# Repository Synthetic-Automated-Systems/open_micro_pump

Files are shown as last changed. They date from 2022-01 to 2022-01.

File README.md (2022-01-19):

# Open Source Microfluidic Pump

Welcome to the official repository for _Open-source, 3D-printed Peristaltic Pumps for Small Volume Point-of-Care Liquid Handling._  This repository serves as an addendum to the paper [Behrens et al.](https://www.nature.com/articles/s41598-020-58246-6) published in Scientific Reports in 2020. This repository hosts the original STL files presented in Behrens et al. (pump 1.0), along with instructions for assembling the pump. Additionally, this repository hosts parts for an updated design (pump 1.1), which provides improved functionality while signifigantly reducing the cost per pump. 
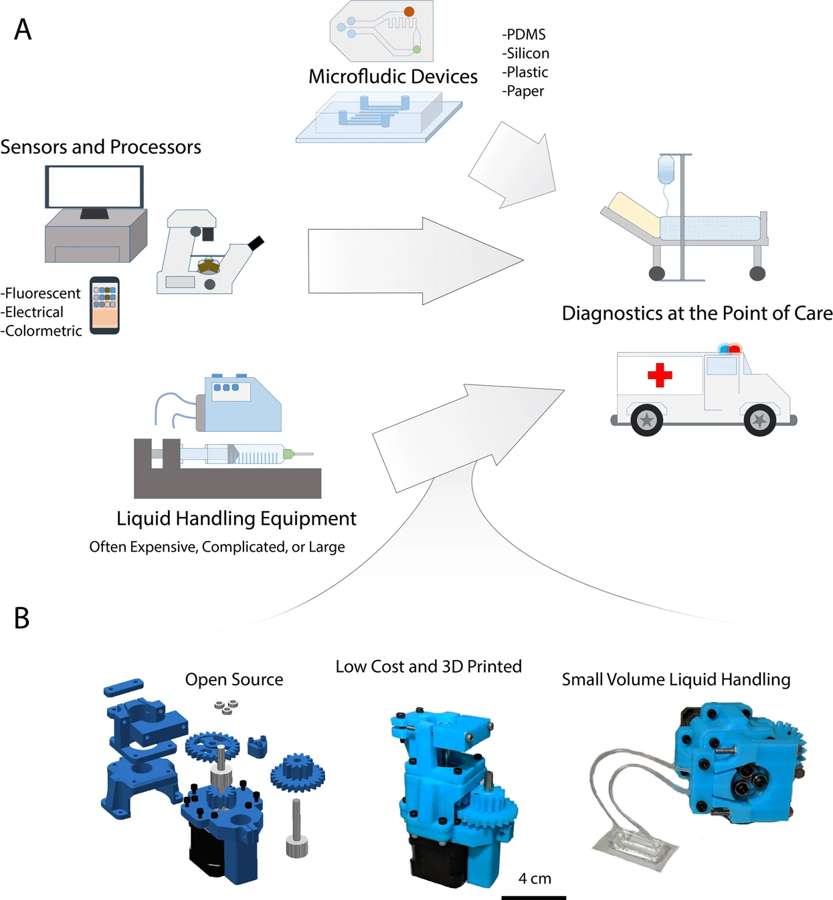
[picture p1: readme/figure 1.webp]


Resources: <b> [Paper available from Scientific Reports](https://www.nature.com/articles/s41598-020-58246-6) 

Authors: Michael Behrens, Haley C. Fuller, Emily R. Swist, Jingwen Wu, Md. Mydul Islam, Zhicheng Long, [Warren Ruder](https://www.engineering.pitt.edu/people/faculty/warren-ruder/)* & [Robert Steward Jr.](https://mae.ucf.edu/person/robert-steward/)*
  
*Corresponding Authors

### Contact:

General questions about this work should be directed to the corresponding authors.
  
Warren Ruder: warrenr[at]pitt[dot]edu
  
Robert Steward: rstewardjr[at]ucf[dot]edu

<br />
<br />
<br />
<br />
<br />
<br />

## Electrical Schematic
This schematic shows how the pump electronics are designed to be connected together. The associated code in this repository is written assuming that this is the physical configuration. 
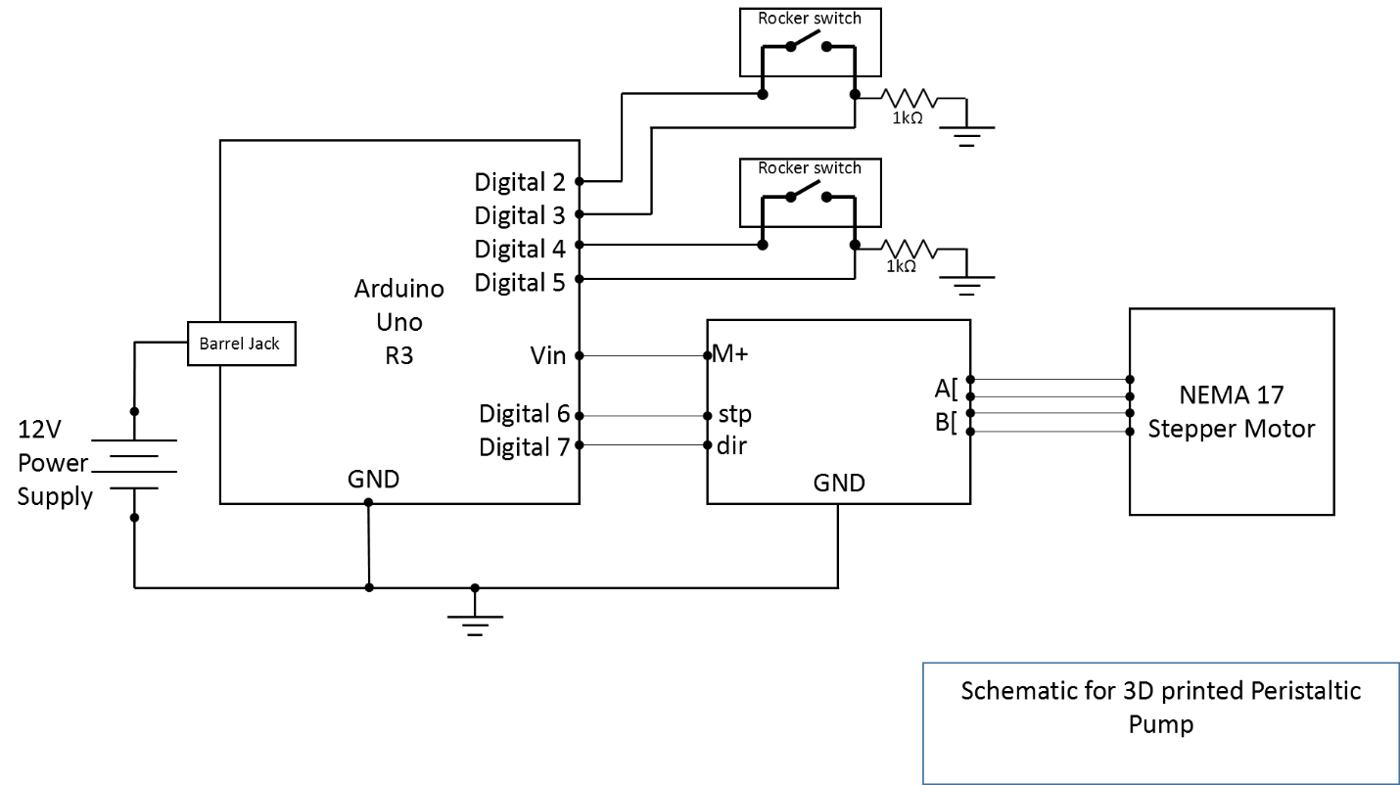
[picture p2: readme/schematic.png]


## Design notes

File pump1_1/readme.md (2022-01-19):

# Pump 1.1 - Improvement on pump presented in Behrens et al. 2020

This is the updated design, which is easier to use, more robust, and cheaper. As of this writing, pump 1.1 is about $100 cheaper to build per unit than pump 1.0.

Here you can find the STL files for 3D printing pump 1.1. The STL files included here are rendered in millimeters. You can also find the parametric CAD files created in Autodesk Inventor if you would like the modify or improve on the design. If you do make any improvements to the pump, we would love it if let us know, and we can share your improved files on this repository!

# Major updates between pump 1.1 and pump 1.0

- The sizes of ball bearing used are more common, so they are much cheaper to purchase. The number of ball bearing used has also been reduced.
- The rotor design is improved to make it easier to build.
- The tube clamp design is improved to create more reproducable clamping pressure on the tubing. Multiple clamp files are provided with different spacer sizes for different clamping pressures. 
- A stock D-profile shaft is used so there is no need to grind a D prifile into the end of the rotor shaft. 
- A 3D printed shaft pusher tool is included to make it easy to fine tune the position of the rotor on the rotor shaft to align it with the tubing.

# Bill of Materials
This list provides suggestions for what to purchase if you would like to build a pump yourself. However, these links might break, or the prices might change since I wrote this, so you might have to swap these parts out for equivalent ones. This list should still point you in the right direction. Some items here are bought in bulk, so if you are building multiple pumps you could save some money. 

| Item  | Quantity | Price | Link |
| --- | --- | --- | --- |
| NEMA 17 40mm 1.8° stepper motor  | 1 | $10.99 | [Amazon](https://www.amazon.com/Twotrees-Nema17-Stepper-17HS4401S-Printer/dp/B07Y2SVNGP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) |
| Hex socket machine screws M3 0.5 x 16 mm | 29 | $6.73 (for pack of 50) | [McMaster Carr](https://www.mcmaster.com/91274A107/) |
| Hex socket machine screws M3 0.5 x 40 mm| 2 | $3.95 (for pack of 25) | [McMaster Carr](https://www.mcmaster.com/91292A024/) |
| M3 0.5 nut | 20 | $1.17 (pack of 100) | [McMaster Carr](https://www.mcmaster.com/90592A085/) |
| 6 mm ID x 19 mm OD x 6 mm width ball bearing | 2 | $7.44 ($3.72 each) | [Grainger](https://www.grainger.com/product/TRITAN-Miniature-Ball-Bearing-Shielded-49DD56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)|
| 0.1875" ID x 0.375" OD x 0.125" width ball bearing | 3 | $18.06 ($6.02 each) | [Grainger](https://www.grainger.com/product/TRITAN-Miniature-Ball-Bearing-Shielded-49DE11)|
| 6 mm x 100 mm steel shaft | 1 | $6.99 | [Amazon](https://www.amazon.com/6mmX100mm-Linear-Motion-Shaft-Diameter/dp/B08HYF2WPX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) |
| D-profile 1/4" diameter steel shaft | 1 | $7.17 | [McMaster Carr](https://www.mcmaster.com/8632T132/)|
| EasyDriver stepper motor driver | 1 | $14.95 | [Sparkfun](https://www.sparkfun.com/products/12779)
| Arduino Uno R3 | 1 | $22.95 | [Sparkfun](https://www.sparkfun.com/products/11021)|
| 1kΩ resistors | 2 | $0.95 (for pack of 20) | [Sparkfun](https://www.sparkfun.com/products/14492)|
| Hookup wire | 1 | $19.95 (for assorted pack) | [Sparkfun](https://www.sparkfun.com/products/11367)|
| Breakaway Headers | 1 | $1.50 | [Sparkfun](https://www.sparkfun.com/products/116)|
| Rocker Switch | 2 | $1.90 ($0.95 each) | [Sparkfun](https://www.sparkfun.com/products/8837)|
| 12V Power Supply | 1 | $8.70 | [McMaster Carr](https://www.mcmaster.com/70235K49/)|
| ABS 3D printer filament | ~200 g | $39.95 (for an 800 g spool) | [Amazon](https://www.amazon.com/Zortrax-Z-ABS-2-3D-Printer-Filament/dp/B08T7VD63K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)|
| Rotary Potentiometer | 1 | $1.18 | [Mouser](https://www.mouser.com/ProductDetail/Bourns/PDB181-K425K-104B?qs=Ivs1Be2ZGq4sYukQEDBRmw%3D%3D)|
| 1 mm ID 3 mm OD 50A silicone tubing | 10 ft | $9.70 ($0.97 per foot) | [McMaster Carr](https://www.mcmaster.com/5054K303/)|
|1/32" ID, 1/16" OD, 50A silicone tubing | 10 ft | $8.20 ($0.82 per foot) | [Mcmaster Carr](https://www.mcmaster.com/5236K204/)|
| Total (the per pump price is lower if building multiple pumps) | | ~ $190 (~$140 if you already have hookup wire and 3D printer filament)  | |

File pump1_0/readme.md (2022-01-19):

# Pump 1.0, Presented in Behrens et al. Scientific Reports 2020

This is the original design, which was preseted in the 2020 paper. This design has been superseded by design 1.1, which is easier to use, more robust, and cheaper. 

Here you can find the STL files for 3D printing. The STL files included here are rendered in millimeters (The original files included with the 2020 paper are rendered in centimeters). The updated files here are functially equivalent, but are more convenient to use with most 3D printer software. 

# Bill of Materials
This list provides suggestions for what to purchase if you would like to build a pump yourself. However, these links might break, or the prices might change since I wrote this, so you might have to swap these parts out for equivalent ones. This list should still point you in the right direction. Some items here are bought in bulk, so if you are building multiple pumps you could save some money. 

| Item  | Quantity | Price | Link |
| --- | --- | --- | --- |
| NEMA 17 40mm 1.8° stepper motor  | 1 | $10.99 | [Amazon](https://www.amazon.com/Twotrees-Nema17-Stepper-17HS4401S-Printer/dp/B07Y2SVNGP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) |
| Hex socket machine screws M3 0.5 x 16 mm | 29 | $6.73 (for pack of 50) | [McMaster Carr](https://www.mcmaster.com/91274A107/) |
| Hex socket machine screws M3 0.5 x 40 mm| 2 | $3.95 (for pack of 25) | [McMaster Carr](https://www.mcmaster.com/91292A024/) |
| M3 0.5 nut | 20 | $1.17 (pack of 100) | [McMaster Carr](https://www.mcmaster.com/90592A085/) |
| 6 mm ID x 17 mm OD x 6 mm width ball bearing (pro tip: save money by building pump version 1.1, which uses much cheaper bearings)  | 4 | $99.36 ($24.84 each) | [McMaster Carr](https://www.mcmaster.com/4668K122/) |
| 3/16" ID 5/16" OD 1/8" width ball bearing | 3 | $20.76 ($6.92 each) | [McMaster Carr](https://www.mcmaster.com/57155K372/) |
| 6 mm x 100 mm steel shaft | 1 | $6.99 | [Amazon](https://www.amazon.com/6mmX100mm-Linear-Motion-Shaft-Diameter/dp/B08HYF2WPX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) |
| EasyDriver stepper motor driver | 1 | $14.95 | [Sparkfun](https://www.sparkfun.com/products/12779)
| Arduino Uno R3 | 1 | $22.95 | [Sparkfun](https://www.sparkfun.com/products/11021)|
| 1kΩ resistors | 2 | $0.95 (for pack of 20) | [Sparkfun](https://www.sparkfun.com/products/14492)|
| Hookup wire | 1 | $19.95 (for assorted pack) | [Sparkfun](https://www.sparkfun.com/products/11367)|
| Breakaway Headers | 1 | $1.50 | [Sparkfun](https://www.sparkfun.com/products/116)|
| Rocker Switch | 2 | $1.90 ($0.95 each) | [Sparkfun](https://www.sparkfun.com/products/8837)|
| 12V Power Supply | 1 | $8.70 | [McMaster Carr](https://www.mcmaster.com/70235K49/)|
| ABS 3D printer filament | ~200 g | $39.95 (for an 800 g spool) | [Amazon](https://www.amazon.com/Zortrax-Z-ABS-2-3D-Printer-Filament/dp/B08T7VD63K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)|
| Rotary Potentiometer | 1 | $1.18 | [Mouser](https://www.mouser.com/ProductDetail/Bourns/PDB181-K425K-104B?qs=Ivs1Be2ZGq4sYukQEDBRmw%3D%3D)|
| 1 mm ID 3 mm OD 50A silicone tubing | 10 ft | $9.70 ($0.97 per foot) | [McMaster Carr](https://www.mcmaster.com/5054K303/)|
|1/32" ID, 1/16" OD, 50A silicone tubing | 10 ft | $8.20 ($0.82 per foot) | [Mcmaster Carr](https://www.mcmaster.com/5236K204/)|
| Total (the per pump price is lower if building multiple pumps) | | ~ $280 (~$230 if you alread have wire and 3D printer filament)  | |

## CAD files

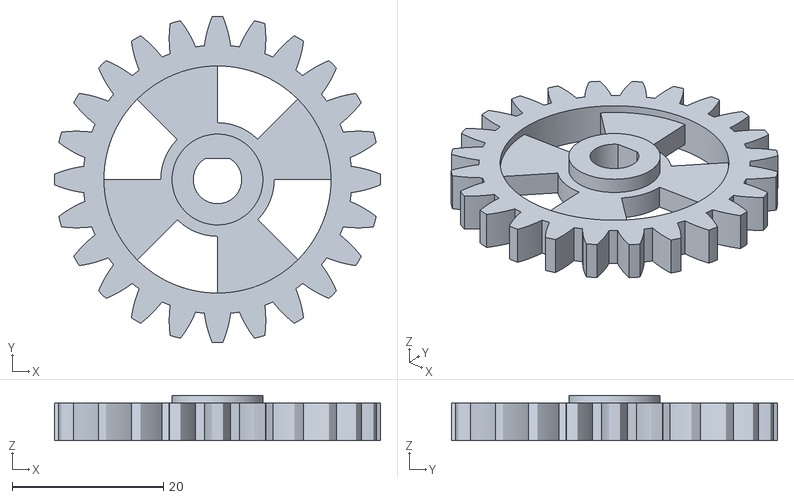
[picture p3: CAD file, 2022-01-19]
pump1_1/parts_files/STL/5 large gear.stl
43.1 x 43.1 x 6.00

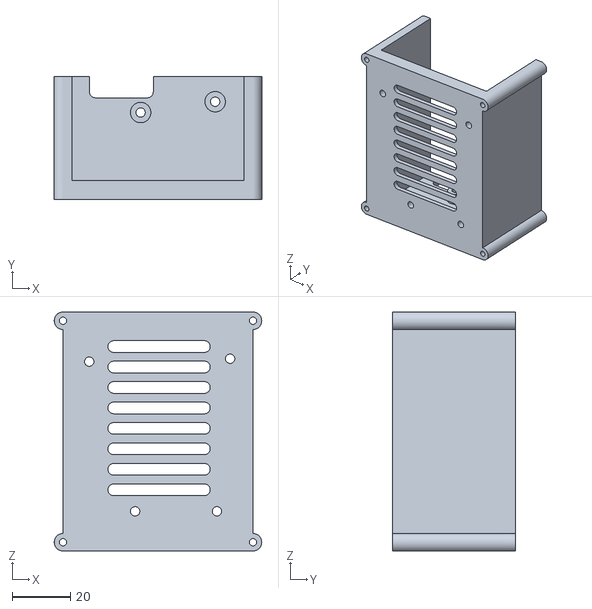
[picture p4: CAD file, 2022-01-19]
pump1_1/parts_files/STL/11 electronics case.stl
71.0 x 42.0 x 81.8

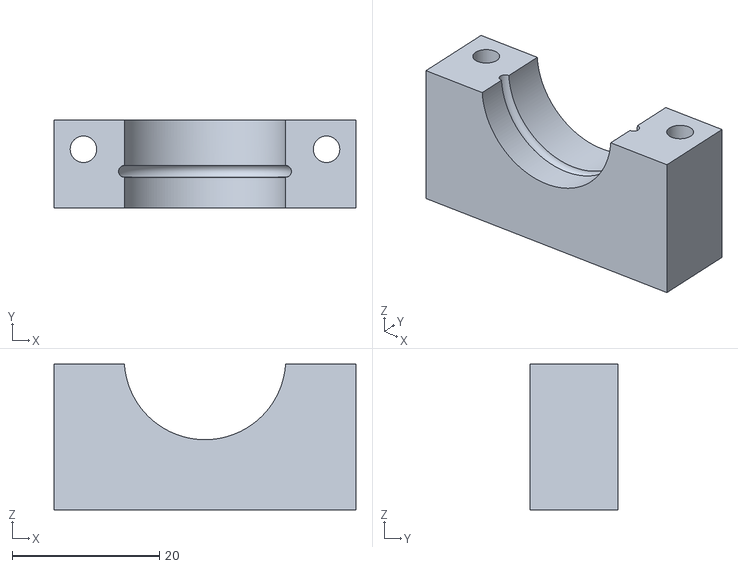
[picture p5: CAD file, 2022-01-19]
pump1_1/parts_files/STL/7 peristaltic pump lid.stl
41.0 x 12.0 x 19.8

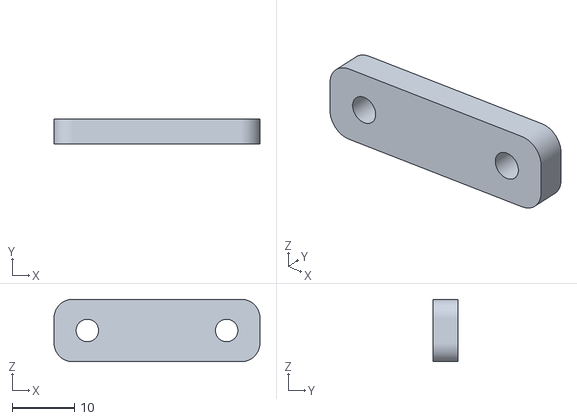
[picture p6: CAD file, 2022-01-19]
pump1_1/parts_files/STL/8 peristaltic pump clamp.stl
33.0 x 4.00 x 10.0

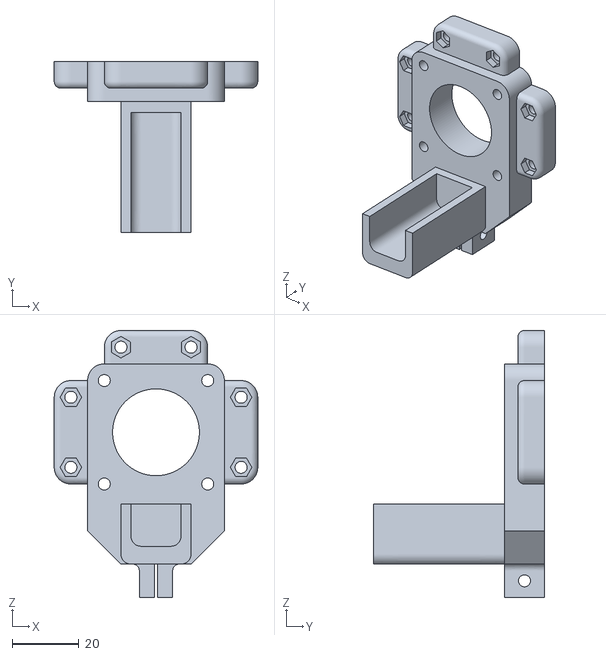
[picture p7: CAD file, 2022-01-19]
pump1_1/parts_files/STL/1 gear box base.stl
61.0 x 51.2 x 80.0

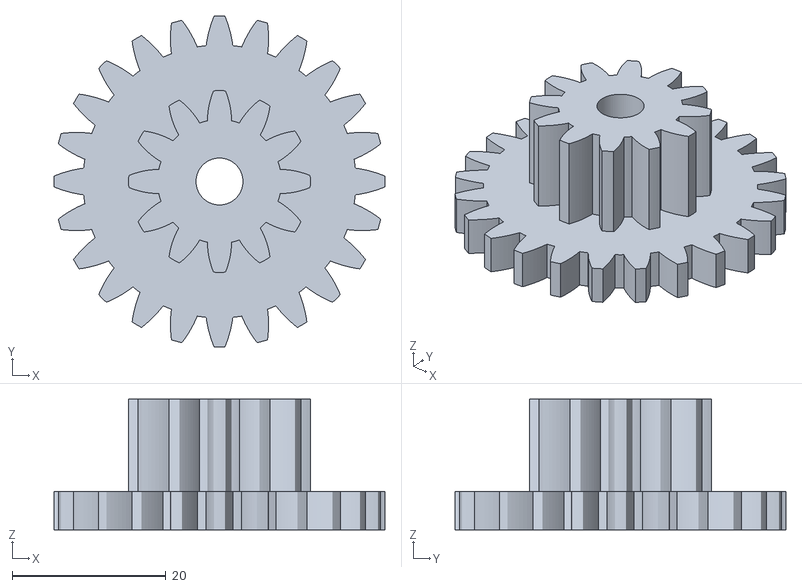
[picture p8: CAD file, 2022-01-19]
pump1_1/parts_files/STL/3 stacked gear.stl
43.1 x 43.1 x 17.0

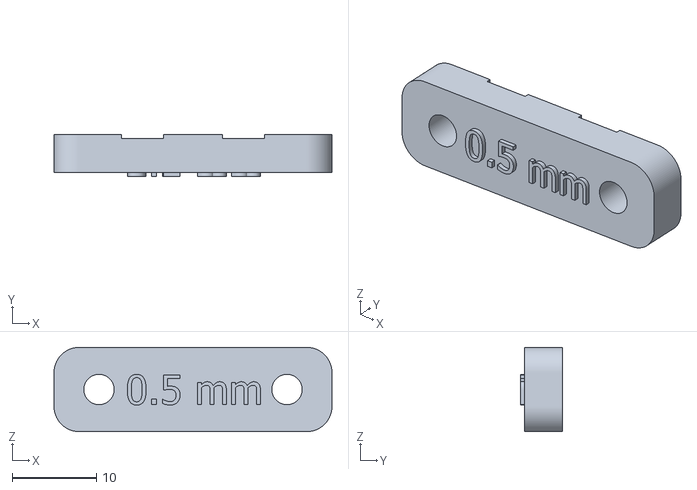
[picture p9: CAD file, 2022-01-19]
pump1_1/parts_files/STL/8 peristaltic pump clamp 0.5mm.stl
33.0 x 5.00 x 10.0

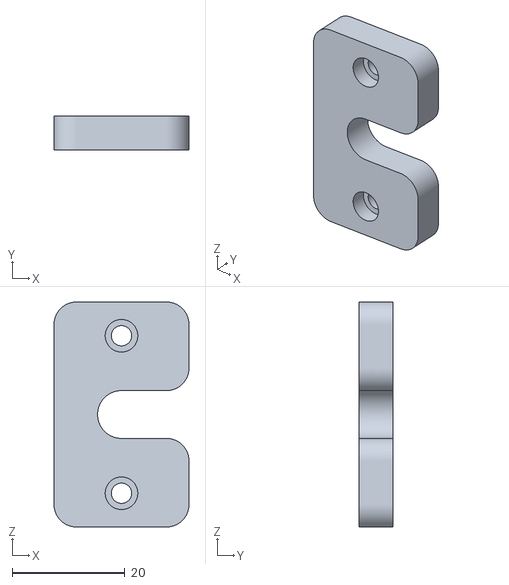
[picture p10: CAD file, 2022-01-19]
pump1_1/parts_files/STL/shaft pusher bottom.stl
24.0 x 6.00 x 40.0

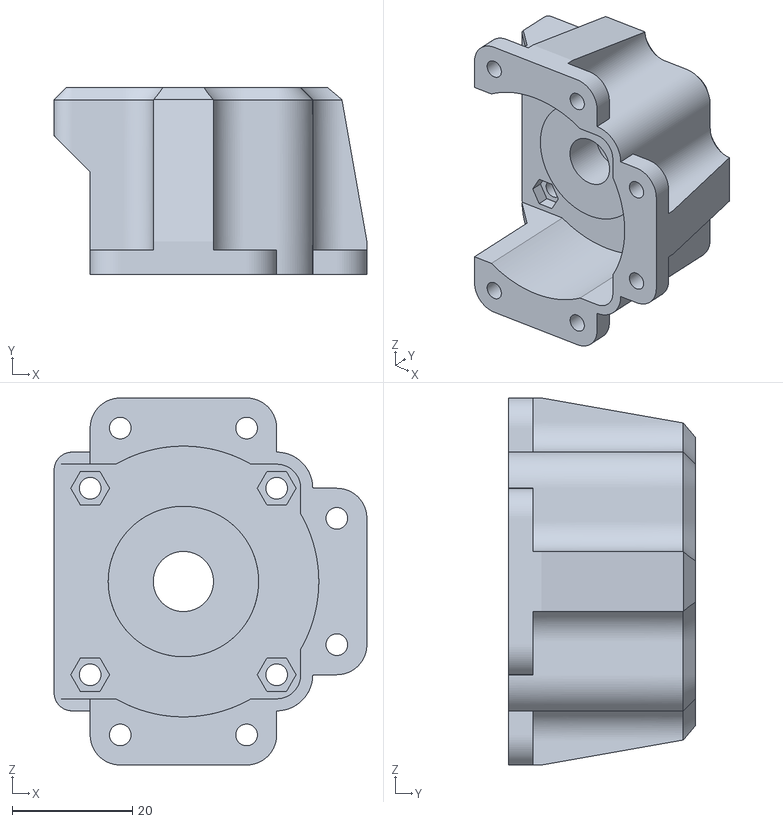
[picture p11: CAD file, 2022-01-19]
pump1_1/parts_files/STL/4 gear box upper case.stl
52.0 x 31.0 x 61.0

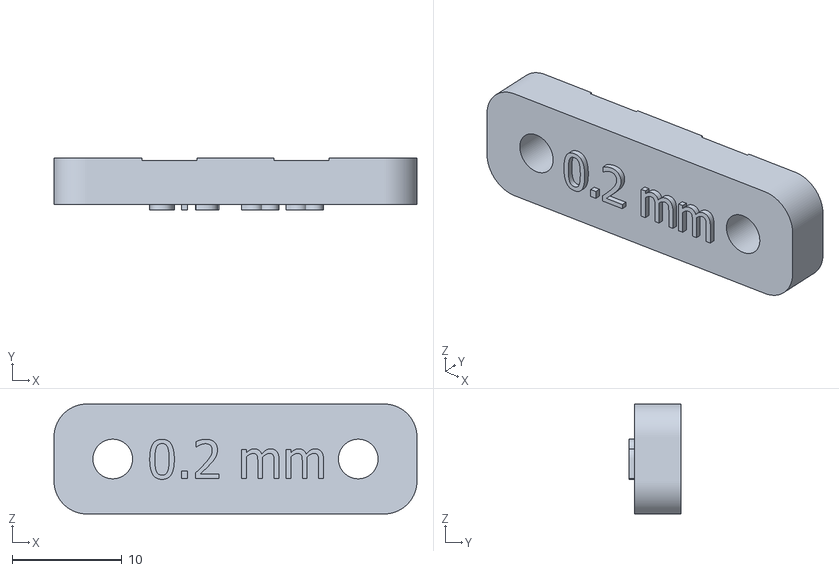
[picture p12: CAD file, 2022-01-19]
pump1_1/parts_files/STL/8 peristaltic pump clamp 0.2mm.stl
33.0 x 4.70 x 10.0

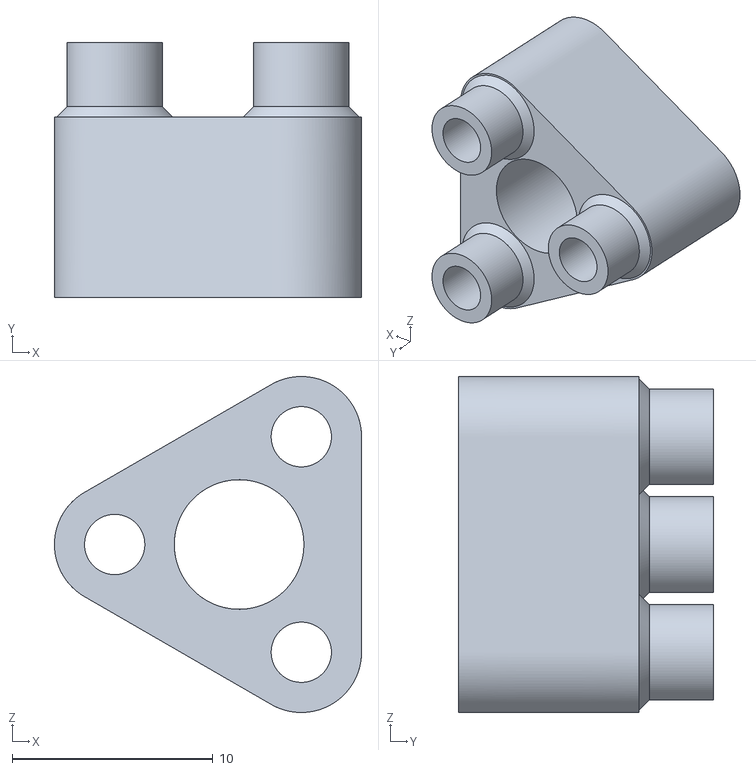
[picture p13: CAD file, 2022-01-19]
pump1_1/parts_files/STL/9 rotor 2.0.stl
15.3 x 12.7 x 16.7

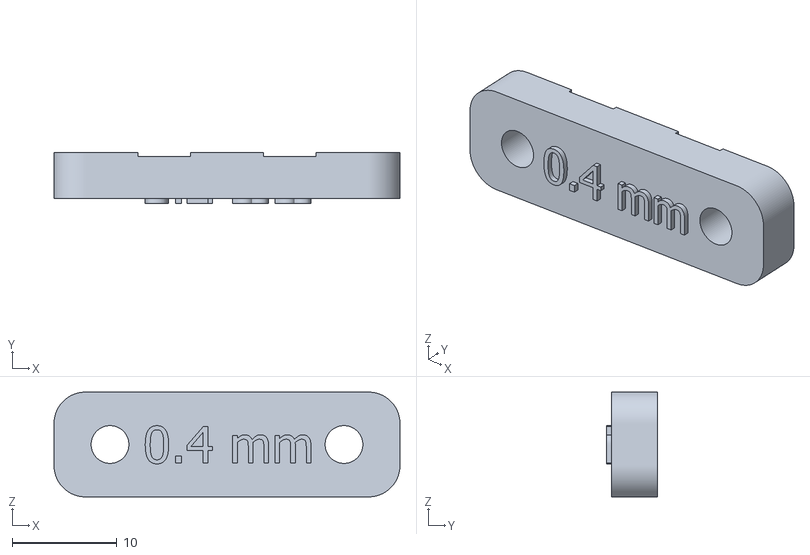
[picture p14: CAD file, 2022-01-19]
pump1_1/parts_files/STL/8 peristaltic pump clamp 0.4mm.stl
33.0 x 4.90 x 10.0

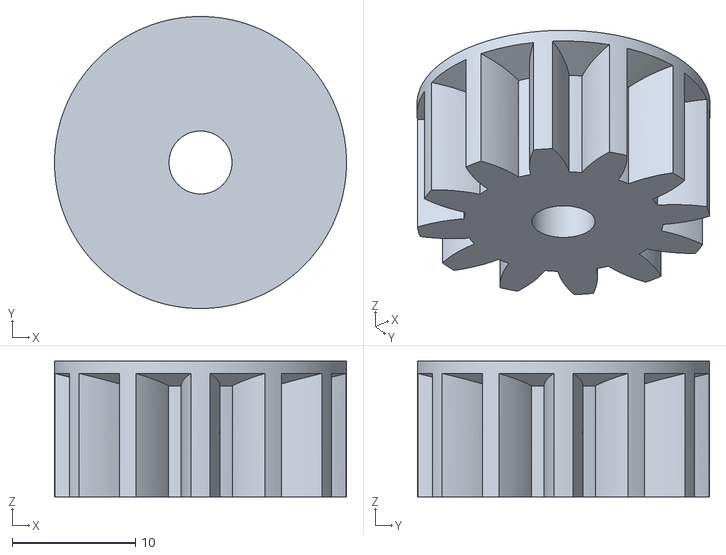
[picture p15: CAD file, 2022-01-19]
pump1_1/parts_files/STL/2 small gear with shelf.stl
23.6 x 23.6 x 11.0

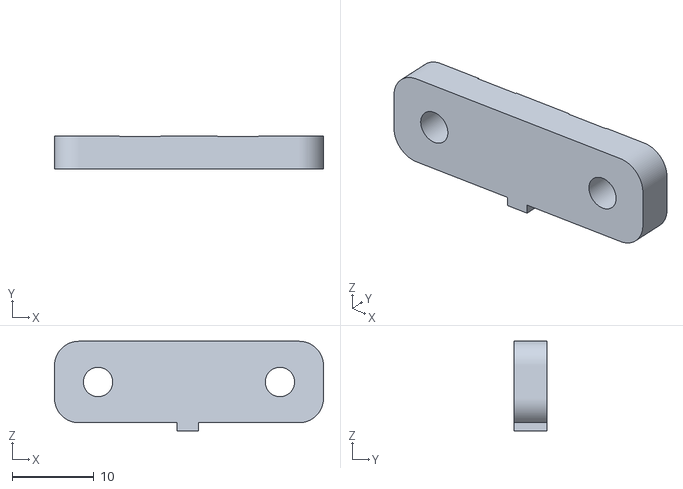
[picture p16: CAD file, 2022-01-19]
pump1_1/parts_files/STL/8 peristaltic pump clamp 0.1mm.stl
33.0 x 4.10 x 11.0

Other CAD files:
pump1_1/parts_files/STL/7 peristaltic pump lid with lip.stl
pump1_1/parts_files/STL/7 peristaltic pump lid 0.3mm shaved off.stl
pump1_1/parts_files/STL/7.1 peristaltic pump lid 3mm.stl
pump1_1/parts_files/STL/6 peristaltic pump stator.stl
pump1_1/parts_files/1 gear box base.ipt
pump1_1/parts_files/11 electronics case.ipt
pump1_1/parts_files/2 small gear with shelf.ipt
pump1_1/parts_files/3 stacked gear.ipt
pump1_1/parts_files/4 gear box upper case.ipt
pump1_1/parts_files/5 large gear.ipt
pump1_1/parts_files/6 peristaltic pump stator.ipt
pump1_1/parts_files/6.1 peristaltic pump stator 3mm.ipt
pump1_1/parts_files/7 peristaltic pump lid with lip2.ipt
pump1_1/parts_files/7.1 peristaltic pump lid 3mm.ipt
pump1_1/parts_files/8 peristaltic pump clamp 0.1mm.ipt
pump1_1/parts_files/8 peristaltic pump clamp 0.2mm.ipt
pump1_1/parts_files/8 peristaltic pump clamp 0.3mm.ipt
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

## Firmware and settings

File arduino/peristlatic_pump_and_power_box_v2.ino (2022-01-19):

//This is a program for running the 3d peristaltic pump designed in the Ruder Lab at Pitt
//This program is designed to be used with the included power box with a direction switch, a power switch, and a potentiometer to sense the speed
//this program can run the pump at a speed set by the potentiometer, change direection, and turn on and off. 
//see the following section of code to see the arduino pins used for this.



#include <Timer.h>

//**********************************************************************************************************************************************************************
//this section of code sets the physical GPIO pins that are used. this must match the hardware setup. 
int stp = 6; //digital pin for outputting step commands
int dir = 7; //digital pin for outputting direction commands
int powerSensor = 3; //digital pin that will take readings from the power switch
int powerSwitchVcc = 2; //digital pin that is always high, to supply Vcc to the power switch (lazy workaround)
int directionSwitch = 4; //digital pin that is always high, to supply Vcc to the direction switch (lazy workaround)
int dirSensor = 5; //digital pin that senses the direction switch
int speedPot = 1; //analog pin that keeps track of the speed knob potentiometer

Timer t1, t2; //two timer objects to run commands at a fixed time interval

float delayTime = 100; //time between steps. changes with the speed sensor potentiometer
unsigned long timeElapsed = 0; //how long it's been since the program started running
int initialized = 0; //variabe that tells you whether of not you have done the acceleration routine for running at high speeds
int onSwitch = 0; //variable that shoud really be gotten rid of and replaced with powerSensorRead
int powerSensorRead = 0; //variable to hold the power sensor reading
int dirSensorRead = 0; //variable to hold readings from the direction sensor
int previousDir = 0; //variable that keeps track of which direction you were going last loop
int speedReading = 0; //variable to keep track of the speed
int previousSpeed = 0; //variable the keeps track of which speed you were going at last loop
float currentTime = 0; //counter that keeps track of the time
int analogReadTiming = 100; //time between readings of the analog potentiometer
int lastPowerRead = 0; //variable to keep track of the state of the power switch


// the setup function runs once when you press reset or power the board
void setup() {
  //set up the digital pins as input or output
  pinMode(stp, OUTPUT);
  pinMode(dir,OUTPUT);
  pinMode(powerSwitchVcc,OUTPUT);
  pinMode(directionSwitch, OUTPUT);
  pinMode(dirSensor,INPUT);
  pinMode(powerSensor, INPUT);

  digitalWrite(dir,HIGH);   //initialize value for direction
  digitalWrite(powerSwitchVcc,HIGH);  //set a digital pin always high for the power switch to use
  digitalWrite(directionSwitch,HIGH); //set a digital pin alwasy high for the direction switch to use
  
  Serial.begin(9600);
  while (!Serial) {
    ;
  }

  t1.every(analogReadTiming, speedSense,0); //read the speed sensor every *analogReadTiming* milliseconds
  t2.every(analogReadTiming, printReading,0); // print the diagnostic string to the terminal. comment out for faster operation
}

// the loop function runs over and over again forever
void loop() {

  //update the timers
  t1.update();
  t2.update();
  
  if (onSwitch == 1)
  {
    if (initialized == 0)
    {
      initialize();
    } 
    if (speedReading != 0)
    {
      digitalWrite(stp, HIGH);   // send a step 1
      delayMicroseconds(delayTime);              //delay for the right amount of time
      digitalWrite(stp, LOW);    // send a step 0, 
      delayMicroseconds(delayTime);              //delay for the right amount of time
    }
   
  }
  takeReading();
  //printReading(); //uncomment this if you want to print the diagnostic information every loop. not recommended for speed reasons. this slows the loop down. 
}

void takeReading() //a function to take readings from the switches
{
  powerSense();
  directionSense();  
}

void powerSense() //a function to sense the state of the power switch
{
    powerSensorRead = digitalRead(powerSensor); //read the power switch
   if(powerSensorRead == HIGH)
  {
    onSwitch = 1;
  }
  else
  {
    onSwitch = 0;
  }
  if (powerSensorRead != lastPowerRead) //if there has been a state transition from low to high on the power switch, set initialized to 0
  {
    if (powerSensorRead == HIGH)
    {
      initialized = 0;
    }
  }
  lastPowerRead = powerSensorRead; //update the last power reading
}

void directionSense() //a function to sense the direcetion switch state
{
   dirSensorRead = digitalRead(dirSensor); //read the direction switch. 
  if (dirSensorRead != previousDir) //run the initilization protocol of the direction switch has flipped.
  {
    initialized = 0;
  }
  previousDir = dirSensorRead; //keep track of the last state of teh direction switch
  if(dirSensorRead == HIGH)
  {
    digitalWrite(dir,HIGH);
  }
  else
  {
    digitalWrite(dir,LOW);
  }
}

void speedSense() //a function to sense the potentiometer and set the speed of the pump
{
  speedReading = analogRead(speedPot); //analog read the potentiometer
  if (abs(speedReading - previousSpeed) > 3) //this is an analog reading so there is a little wiggle room (3 bits out of 1024). if the change is less than 3 assume that no change has been made
  {
    initialized = 0;
  }
  previousSpeed = speedReading;
  delayTime = (20460/speedReading); //thisis the function to determine how long the loop runs for.
}

void printReading() //a function to print diagnostic information to the terminal
{
  currentTime = millis();
  String Output = String(String(onSwitch) + ", " + String(speedReading));
  Serial.println(Output);
}

void initialize() //a function that is used to accelerate the motor slowly, so that there is not a hardware problem with fast speeds. This is to compensate for the inertia of the rotor. 
{
  
 for (int i = 300; i > 0; i--) 
      {
        if(speedReading != 0)
        {
          digitalWrite(stp, HIGH);   // turn the LED on (HIGH is the voltage level)
          delayMicroseconds(delayTime+i);             //increase the delay each loop to help the pump accelerate
          digitalWrite(stp, LOW);    // turn the LED off by making the voltage LOW
          delayMicroseconds(delayTime+i);             // increase the delay each loop to help the pump accelerate
        }
      }
      initialized = 1; 
}

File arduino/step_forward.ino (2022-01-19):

/*
 * this program is to control the peristaltic pump to step the fluid a set amount forward on command from a switch
 */

//Input the Frequency . Do not exceed 2.

float frequency = 1


//**********************************************************************************************************************************************************************
float loopTime = (639.6/frequency-287.8); 
float delayTime = loopTime/2; 
unsigned long timeElapsed = 0;
int stp = 6;
int dir = 7;
int initialized = 0;
int power = 1;
int onSwitch = 0;
int sensor = 2;
int powerSwitch = 3;
int sensorRead = 0;
int directionSwitch = 5;
int dirSensor = 4;
int dirSensorRead = 0;
int previousDir = 0;

int valve = 8;
long j = 0;
int valveState = 1;

long previousMillis = 0;
long interval = 2000;
int a = 60;

// the setup function runs once when you press reset or power the board
void setup() {
  // initialize digital pin 13 as an output.
  pinMode(stp, OUTPUT);
  pinMode(dir,OUTPUT);
  pinMode(powerSwitch,OUTPUT);
  pinMode(directionSwitch, OUTPUT);
  pinMode(dirSensor,INPUT);
  pinMode(sensor, INPUT);
  pinMode(valve,OUTPUT);
  digitalWrite(dir,HIGH);
  digitalWrite(powerSwitch,HIGH);
  digitalWrite(directionSwitch,HIGH);
  digitalWrite(valve,HIGH);
  
  Serial.begin(250000);
  while (!Serial) {
    ;
  }
}

// the loop function runs over and over again forever
void loop() {

  takeReading();

  
}

void takeReading()
{
  sensorRead = digitalRead(sensor);
   if(sensorRead == HIGH)
  {
    onSwitch = 1;
  }
  else
  {
    onSwitch = 0;
    initialized = 0;
  }

  dirSensorRead = digitalRead(dirSensor);
  if (dirSensorRead != previousDir)
  {
    initialized = 0;
  }
  previousDir = dirSensorRead;
  if(dirSensorRead == HIGH)
  {
    //digitalWrite(dir,HIGH);
    for (int i = 4000; i > 0; i--) 
      {
        digitalWrite(stp, HIGH);   // turn the LED on (HIGH is the voltage level)
        delayMicroseconds(100);              // wait for a second
        digitalWrite(stp, LOW);    // turn the LED off by making the voltage LOW
        delayMicroseconds(100);              // wait for a second
      }
    while (dirSensorRead == HIGH)
    {
      dirSensorRead = digitalRead(dirSensor);
    }
  }
  else
  {
    //digitalWrite(dir,LOW);
  }
 
  
}
